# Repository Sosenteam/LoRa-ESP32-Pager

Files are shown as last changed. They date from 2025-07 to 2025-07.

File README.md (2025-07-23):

# LoRa-ESP32-Pager

This is a ESP-32 and SX1262 based pager, It contains full battery charging and management as well as an input keypad and encoder. It uses a 0.96" Oled (SSD1306).
There isn't any case because I wanted it to be a PCB only handheld (like the sprig), but I may laser cut a back when I get access to a laser cutter again (2 months).
The firmware is based on meshatastic, and hopefully will be able to use other meshtastic nodes to forward/mesh messages. 

I decided to build this because I felt like me and my friend group were too dependant on our phones, so I wanted to make a way to communicate that didn't involve phones. Also hopefully will be able to fully replace phones at school, which is aligned with my school possibly banning phones this upcoming year. The other main reason I wanted to start this project is because I wanted to learn more about radio and LoRa technology. This was also my first experience building my own PCBs, so I chose this over other projects because It would allow me to work with them.





|Name |Use |Qty|Total Price|Link |
|---|---|---|---|---|
|Oled Screen |Screen |5  |$9.80 |https://www.aliexpress.us/item/3256808552064563.html |
|Battery |Battery |5  |$23 |https://www.aliexpress.us/item/3256808031709894.html |
| | | | | |
|Ra-01SH |LoRa |5  |16.9 |https://www.aliexpress.us/item/3256802374880132.html |
|MCP73871-2CCI/ML |Battery Management |5  |8.7 |https://www.aliexpress.us/item/3256809154370435.html |
|ESP32-S3-WROOM-1 |ESP32 |5  |20.6 |https://www.aliexpress.us/item/3256808569536766.html |
|TPS63001DRCR |5v to 3v3 |5  |5.17 |https://www.aliexpress.us/item/3256806783602774.html (63001) |
|EC11E1834403 |Rotary Encoder |5  |4.14 |https://www.aliexpress.us/item/2251832760130101.html |
|TYPE-C 16PIN 2MD(073)  |Usb Plug |5  |2.69 |https://www.aliexpress.us/item/3256805314003507.html |
|All Resistors |R100Ω | |4.74 |https://www.aliexpress.us/item/3256806810055728.html (Buy 2-3) |
|Inductor 0805 2.2uH |Inductor for TPS63 |5  |1.45 |https://www.aliexpress.us/item/3256802926211468.html (2.2uH) |
|Leds |Battery Charge Leds  |10 |3.6 |https://www.aliexpress.us/item/2251832152971926.html |
|Diode 1N5819W |Diode for Usb Power  |5  |0.23 |https://www.digikey.com/en/products/detail/tdk-corporation/MLP2012H2R2MT0S1/4327857|
|Ph2.0 Battery Connector|Battery Charger |5  |1.45 |https://www.aliexpress.us/item/3256807255498839.html |
|PTS815SJM250SMTRLFS |Reset and Boot Button|10 |1.15 |https://www.digikey.com/en/products/detail/c-k/PTS815SJM250SMTRLFS/9947846 |
|6x6 Tact Switch |Keypad Buttons |3  |1.29 |https://www.aliexpress.us/item/3256802301084670.html |
|Capacitor Set |Decoupling |1  |8.2 |https://www.aliexpress.us/item/3256807290577536.html (Buy 2-3) |
|Diode LESD |ESD protection diodes|3  |3.34 |https://www.aliexpress.us/item/3256806903277344.html |
|Antenna |Ra-01SH antenna |5  |8.44 |https://www.aliexpress.us/item/3256805050972049.html |
|PCB |PCBs |5  |5 | |
|Ali Express Shipping | | |27 | |
|PCB Way Shipping | | |15 | |
|Digikey Shipping | | |7 | |
| | | |$178.89 | |

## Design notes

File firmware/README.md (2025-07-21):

# This is all TEST code, I can't write the meshtastic firmware untill I get the parts (I don't have this module or ESP32-s3).

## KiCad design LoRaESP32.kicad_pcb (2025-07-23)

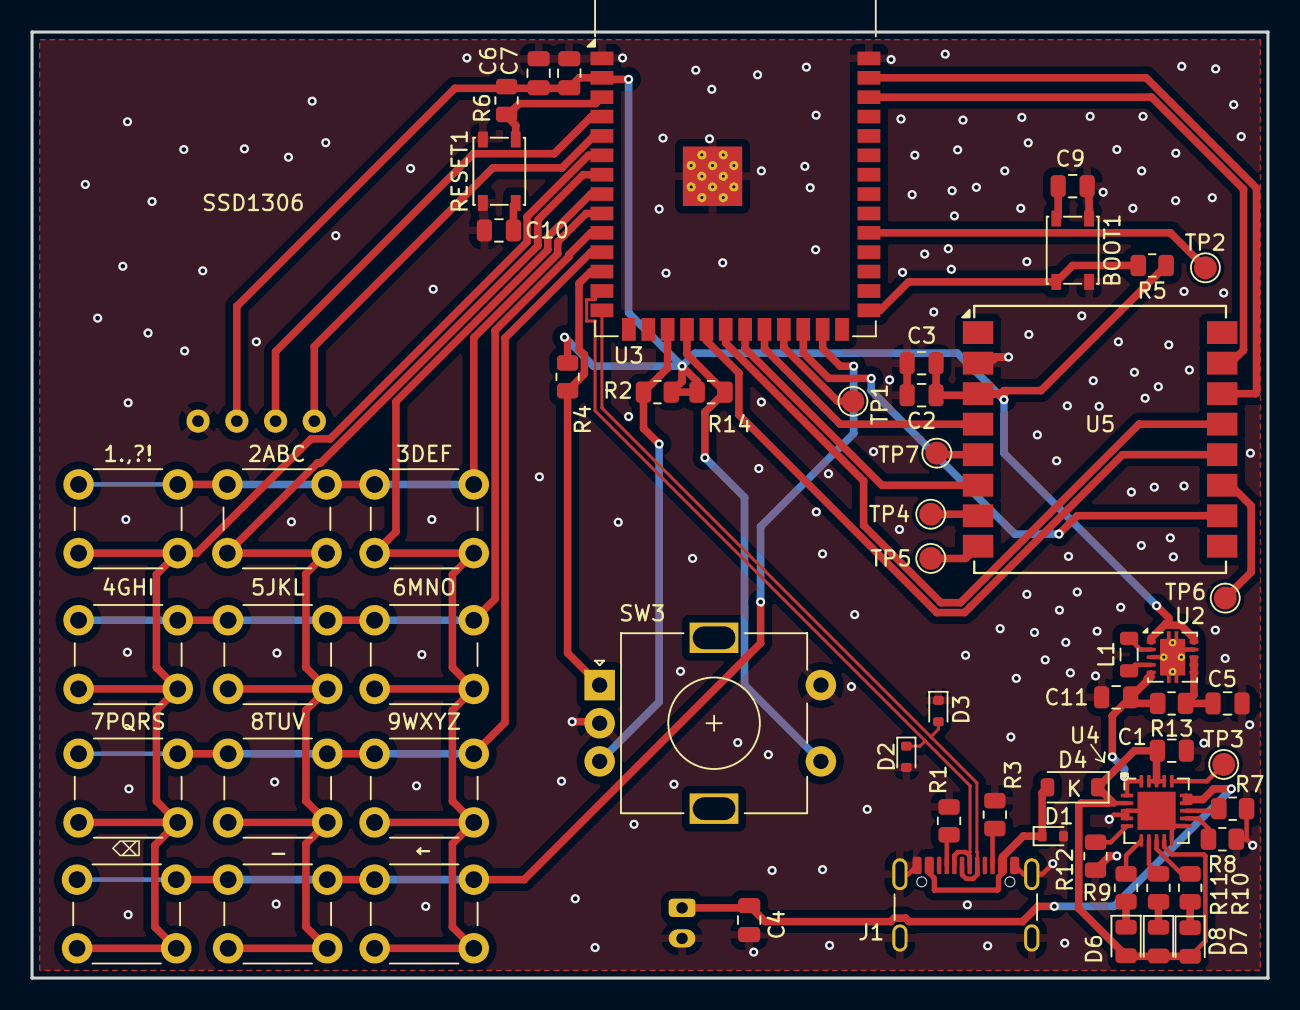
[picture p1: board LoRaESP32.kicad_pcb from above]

Board: 2 copper layers, 81.0 x 62.0 mm, 61 parts (1 on the bottom side), 50 nets.

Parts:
1.,?!, 2ABC, 3DEF, 4GHI, 5JKL, 6MNO, 7PQRS, 8TUV, 9WXYZ: B3SL-1002P; SW_PUSH_6mm
BOOT1: PTS815SJM250SMTRLFS; SW_SPST_PTS810
BT1: B2B-PH-K-S(LF)(SN); JST_PH_B2B-PH-K_1x02_P2.00mm_Vertical
C1, C2, C7, C11: 0805W106K250CC; C_0805_2012Metric
C3, C5, C6, C9, C10: 0805B104K500BD; C_0805_2012Metric
C4: 0805B475K250CC; C_0805_2012Metric
D1, D2, D3: LESD5D5.0CT1G; D_SOD-523
D4: 1N5819W; D_SOD-123
D6: LS R976-NR-1-0-20-R18; LED_0805_2012Metric
D7, D8: LY R97xLG R971-KN-1-0-20-R18; LED_0805_2012Metric
J1: TYPE-C 16PIN 2MD(073); USB_C_Receptacle_GCT_USB4105-xx-A_16P_TopMnt_Horizontal
L1: MLP2012 MLP2012H2R2MT0S1; L_0805_2012Metric
R1, R3: RC0805JR-075K1L; R_0805_2012Metric
R2, R4, R5, R6, R7, R8, R12, R14: RMCF0805FT10K0; R_0805_2012Metric
R9, R10, R11: CRGCQ0805J470R; R_0805_2012Metric
R13: RC0805FR-07100RL; R_0805_2012Metric
RESET1: PTS815SJM250SMTRLFS; SW_SPST_PTS810
SSD1306: SSD1306
SW3: EC11E1834403; RotaryEncoder_Alps_EC11E-Switch_Vertical_H20mm
TP1: TEST_GPIO_21; TestPoint_Pad_D1.5mm
TP2: TEST_GPIO_38; TestPoint_Pad_D1.5mm
TP3: BatTest; TestPoint_Pad_D1.5mm
TP4: DIO2; TestPoint_Pad_D1.5mm
TP5: DIO3; TestPoint_Pad_D1.5mm
TP6: RXEN; TestPoint_Pad_D1.5mm
TP7: TXEN; TestPoint_Pad_D1.5mm
U2: TPS63001; Texas_DRC0010J_ThermalVias
U3: ESP32-S3-WROOM-1
U4: MCP73871-2CC; QFN-20-1EP_4x4mm_P0.5mm_EP2.5x2.5mm
U5: Ra-01SH; Ai-Thinker-Ra-01-LoRa
_: B3SL-1002P; SW_PUSH_6mm
←: B3SL-1002P; SW_PUSH_6mm
⌫: B3SL-1002P; SW_PUSH_6mm

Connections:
+3V3: C2.1, C3.1, C6.1, C7.1, R2.2, R4.1, R5.1, R6.1, R14.1, SSD1306.2 (VCC), U2.1 (VOUT), U2.10 (FB), U3.2 (3V3), U5.3 (VDD)
+5V: C1.1, D4.1 (K), D6.2 (A), D7.2 (A), D8.2 (A), U4.2 (VPCC), U4.9 (~TE), U4.17 (CE), U4.18 (IN), U4.19 (IN)
CHIP_PU: C10.2, R6.2, RESET1.2, U3.3 (EN)
Col1: 1.,?!.2, 4GHI.2, 7PQRS.2, U3.6 (IO6), ⌫.2
Col2: 2ABC.2, 5JKL.2, 8TUV.2, U3.7 (IO7), _.2
Col3: 3DEF.2, 6MNO.2, 9WXYZ.2, U3.8 (IO15), ←.2
D+: D3.2 (A2), J1.A6 (D+), J1.B6 (D+), U3.14 (IO20)
D-: D2.1 (A1), J1.A7 (D-), J1.B7 (D-), U3.13 (IO19)
EncoderA: R4.2, SW3.A, U3.12 (IO8)
EncoderB: R2.1, SW3.B, U3.17 (IO9)
EncoderSW: R14.2, SW3.S1, U3.18 (IO10)
GND: BOOT1.1, BT1.2 (-), C1.2, C2.2, C3.2, C4.1, C5.2, C6.2, C7.2, C9.1, C10.1, C11.1, D1.2 (A2), D2.2 (A2), D3.1 (A1), J1.A1 (GND), J1.A12 (GND), J1.B1 (GND), J1.B12 (GND), J1.S1 (SHIELD), R1.2, R3.2, R7.1, R8.1, R12.1, RESET1.1, SSD1306.1 (GND), SW3.C, SW3.S2, U2.3 (PGND), U2.9 (GND), U2.11 (PGND), U3.1 (GND), U3.40 (GND), U3.41 (GND), U4.3 (SEL), U4.4 (PROG2), U4.10 (V_{SS}), U4.11 (V_{SS}), U4.21 (V_{SS}), U5.2 (GND)
GPIO_0: BOOT1.2, C9.2, R5.2, U3.27 (IO0)
LoraBUSY: U3.24 (IO47), U5.10 (BUSY)
LoraDIO1: U3.21 (IO13), U5.6 (DIO1)
LoraMISO: U3.20 (IO12), U5.13 (MISO)
LoraMOSI: U3.39 (IO1), U5.14 (MOSI)
LoraNSS: U3.38 (IO2), U5.15 (~NSS)
LoraRST: U3.22 (IO14), U5.4 (~RESET)
LoraSCK: U3.19 (IO11), U5.12 (SCK)
unnamed: BT1.1 (+), C4.2, U4.14 (V_{BAT}), U4.15 (V_{BAT})
unnamed: D1.1 (A1), D4.2 (A), J1.A4 (VBUS), J1.A9 (VBUS), J1.B4 (VBUS), J1.B9 (VBUS)
unnamed: D6.1 (K), R9.2
unnamed: D7.1 (K), R10.2
unnamed: D8.1 (K), R11.1
unnamed: J1.A5 (CC1), R1.1
unnamed: J1.B5 (CC2), R3.1
unnamed: C5.1, R13.1, U2.6 (EN), U2.7 (PS/SYNC), U2.8 (VINA)
unnamed: L1.2, U2.4 (L1)
unnamed: L1.1, U2.2 (L2)
unnamed: C11.2, R13.2, U2.5 (VIN), U4.1 (OUT), U4.20 (OUT)
unnamed: TP1.1, U3.23 (IO21)
unnamed: TP2.1, U3.31 (IO38)
unnamed: R7.2, U4.13 (PROG1)
unnamed: R8.2, U4.12 (PROG3)
unnamed: R10.1, U4.8 (STAT1/~LBO)
unnamed: R11.2, U4.7 (STAT2)
unnamed: R12.2, U4.5 (THERM)
unnamed: TP3.1, U4.16 (V_{BAT_SENSE})
unnamed: R9.1, U4.6 (~PG)
unnamed: TP4.1, U5.7 (DIO2)
unnamed: TP5.1, U5.8 (DIO3)
unnamed: TP6.1, U5.11 (RXEN)
unnamed: TP7.1, U5.5 (TXEN)
OledSCL: SSD1306.3 (SCL), U3.4 (IO4)
OledSDA: SSD1306.4 (SDA), U3.5 (IO5)
Row1: 1.,?!.1, 2ABC.1, 3DEF.1, U3.9 (IO16)
Row2: 4GHI.1, 5JKL.1, 6MNO.1, U3.10 (IO17)
Row3: 7PQRS.1, 8TUV.1, 9WXYZ.1, U3.11 (IO18)
Row4: U3.25 (IO48), _.1, ←.1, ⌫.1

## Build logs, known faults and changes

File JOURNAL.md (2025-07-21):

---
title: "LoRa ESP32 Pager"
author: "sosenteam"
description: "A P2P bidirectional pager using ESP32 and LoRa."
created_at: "2025-07-11"
---

# Total Time:  56.5 Hours

## 6/27/2025 (5 Hours)

First day working on this project!! I started by spending two-ish hours reading the specs on LoRa and learning the protocal.
[Amazing Tutorial for LoRa](https://www.circuitstate.com/tutorials/interfacing-ra-01-ra-02-sx1278-lora-modules-with-esp32-using-arduino/) -
[Module Spec Sheet](https://docs.ai-thinker.com/en/lora/man) -
[API Spec Sheet](https://github.com/sandeepmistry/arduino-LoRa/blob/master/API.md)

Afterwords I built the first prototype on a breadboard and got everything wired up.
Next, I messed around with the Arduino library for a while until I was able to send a message from one esp32 and receive it on my RTLSDR v4. Once I was able to send messages, I then built and wired an identical second prototype and got it to receive messages. After way too much tweaking, I was finally able to use a button to send a message from one to the other!

Picture of the protoypes (aren't they adorable):

LoRa Testing

## 6/28/2025 (2 Hours)

More research on how to display a UI! I picked out two SSD1306 modules (pictured above) I had on hand and decided to use them as my displays. I didn't want to manually code the entire UI so I started researching a less code-y solution. I discovered LVGL and Squareline Studio and starting setting them up, followed some Demo projects, read documentation etc.

## 6/29/2025 (2 Hours)

Started designing UI in Squareline Studio, got a first draft of the menu scren and started working on character selection with an encoder. I learned pretty quickly that Squareline studio is built for different projects, and it was also not very intuative to me.



## 7/01/2025 (1 Hour)

Continued work on the UI, focusiing on the read section (where incoming messages wil appear). Struggled a bit with getting the style how I wanted (not supposed to have blue), but overall happy with result.



## 7/04/2025 (2 Hours)

More UI Work! Got a finished version of the UI, with a send screen! Also has 'working' buttons, meaning the back buttons and main menu buttons now bring you to their respective pages. Exported to Arduino IDE!



## 7/05/2025 (1 Hour)

Disaster Struck! LVGL code is not built for the Arduino IDE (prefers the espressif IDE), and the libraries for Arduino are built for ESPI_TFT, which doesn't support my display.
Picture of what Squareline studio gave me:



#### 5 day skip from lack of motavation ):

## 7/10/2025 (3 Hours)

More reasearch done! I've decided to use the MUI library from the u8g2 library, because I've used u8g2 before for projects, and MUI has the encoder code setup!!!
I've also spent a while testing MUI and making and testing examples. Also added encoder to one prototype!

LoRa Update

## 7/11/2025 (2 Hours)

Lots more testing, Struggling with getting the screen to update quickly and also getting the encoder to have faster recognition/acceleration.

## 7/12/2025 (3 Hours)

Resolution!!! I figured out that in order to make the screen refresh faster, I needed to use hardware I2C instead of software I2C. I had to change a single character in my code from a S to a H. (So frustrating).
Also got a good demo for character selection, 12 characters, typing is 100x faster but still not quite perfect. I would like to get rid of Caps if I can. 

PXL_20250712_212104544 RAW-01 MP COVER

## 7/13/2025 (3 Hours)

Started work in KiCAD, lots of watching tutorials, and finding out how to use the editor. Started adding components to my schematic, such as ESP32, voltage regulator, etc.

## 7/14/2025 (3 Hours)

Lots more work in KiCAD, also lots of reading documentation/spec sheets. Started the power supply section, also picked out the ESP32-S3-WROOM-1 because it doesn't need a seperated UART>USB connector.



## 7/15/2025 (4.5 Hours)

So much more KiCAD, got USB and ESP32 and button sections of pcb done, started research into possible battery charging chips/boards (so scary).



 Also started figuring out placement for the board even though it's not great (not finished ofc).



## 7/16/2025 (4 Hours)

Redid entire power section, changed battery chip and voltage regulator chip. Added custom OLED, and also a button matrix. Also started hooking up everything to the ESP32 S3 Wroom.
 

## 7/17/2025 (3 Hours)

Pain. I realised that all my connections were net labels instead of global labels, so I had to redo them all. I added more decoupling caps, testing pads and battery connectors.



Also restarted the layout process and started grouping all my components (whitebox is hopeful final size)

## 7/18/2025 (5 Hours)

Lots of working on layouts. I did a first try of the layout, but I didn't know how to use ground planes so it wasn't very effective. Second draft went way better! I have a completed version, and have sent out pictures/information to Hackclub, KiCAD discord and r/PCB on reddit. Already have found a bunch of small things to fix!





## 7/19/2025 (5 Hours)

Spent the first half of today adressing most of the problems from my first draft. This included fixing symbols, rearranging pins on the ESP32 and adding pullups.
Afterwords I did a full do-over of my PCB layout, and made one more compact and simple. (also started looking into PCB pricing) 




## 7/20/2025 (4 Hours)

Discovered Meshtastic, and decided to attempt to make my board compatible w/ it. Ended up changing Ra-01 to Ra-01sh (diffrent LoRa Module). Redid some of layout (ADDED SO MANY VIAS), started looking into custom firmware.
Also uploaded to PCBway to see prices. (JLCPCB thinks its gonna be $300!!!).


## 7/21/2025 (4 Hours)

Looking at part sourcing, PCBway also wants $88 flat fee for assembly. Decided to assemble myself (scary). Some small pcb adjustments (for EMF), mostly spent today looking through AliExpress to find parts. Made a BOM and finished the rest of my Github repo so I can submit!!! 🎉

Final Pic:



### Thanks for reading all my random ramblings and progress updates!!

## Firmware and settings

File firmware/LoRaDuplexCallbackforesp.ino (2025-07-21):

/*
  LoRa Duplex communication wth callback

  Sends a message every half second, and uses callback
  for new incoming messages. Implements a one-byte addressing scheme,
  with 0xFF as the broadcast address.

  Note: while sending, LoRa radio is not listening for incoming messages.
  Note2: when using the callback method, you can't use any of the Stream
  functions that rely on the timeout, such as readString, parseInt(), etc.

  created 28 April 2017
  by Tom Igoe
*/
#include <SPI.h>              // include libraries
#include <LoRa.h>

#ifdef ARDUINO_SAMD_MKRWAN1300
#error "This example is not compatible with the Arduino MKR WAN 1300 board!"
#endif

const int csPin = 5;          // LoRa radio chip select
const int resetPin = 2;       // LoRa radio reset
const int irqPin = 4;         // change for your board; must be a hardware interrupt pin

String outgoing;              // outgoing message
byte msgCount = 0;            // count of outgoing messages
byte localAddress = 0xBB;     // address of this device
byte destination = 0xFF;      // destination to send to
long lastSendTime = 0;        // last send time
int interval = 2000;          // interval between sends

void setup() {
  Serial.begin(115200);                   // initialize serial
  while (!Serial);

  Serial.println("LoRa Duplex with callback");

  // override the default CS, reset, and IRQ pins (optional)
  LoRa.setPins(csPin, resetPin, irqPin);// set CS, reset, IRQ pin

  if (!LoRa.begin(433E6)) {             // initialize ratio at 915 MHz
    Serial.println("LoRa init failed. Check your connections.");
    while (true);                       // if failed, do nothing
  }

  LoRa.onReceive(onReceive);
  LoRa.receive();
  Serial.println("LoRa init succeeded.");
}

void loop() {
  if (millis() - lastSendTime > interval) {
    String message = "HeLoRa World!";   // send a message
    sendMessage(message);
    Serial.println("Sending " + message);
    lastSendTime = millis();            // timestamp the message
    interval = random(2000) + 1000;     // 2-3 seconds
    LoRa.receive();                     // go back into receive mode
  }
}

void sendMessage(String outgoing) {
  LoRa.beginPacket();                   // start packet
  LoRa.write(destination);              // add destination address
  LoRa.write(localAddress);             // add sender address
  LoRa.write(msgCount);                 // add message ID
  LoRa.write(outgoing.length());        // add payload length
  LoRa.print(outgoing);                 // add payload
  LoRa.endPacket();                     // finish packet and send it
  msgCount++;                           // increment message ID
}

void onReceive(int packetSize) {
  if (packetSize == 0) return;          // if there's no packet, return

  // read packet header bytes:
  int recipient = LoRa.read();          // recipient address
  byte sender = LoRa.read();            // sender address
  byte incomingMsgId = LoRa.read();     // incoming msg ID
  byte incomingLength = LoRa.read();    // incoming msg length

  String incoming = "";                 // payload of packet

  while (LoRa.available()) {            // can't use readString() in callback, so
    incoming += (char)LoRa.read();      // add bytes one by one
  }

  if (incomingLength != incoming.length()) {   // check length for error
    Serial.println("error: message length does not match length");
    return;                             // skip rest of function
  }

  // if the recipient isn't this device or broadcast,
  if (recipient != localAddress && recipient != 0xFF) {
    Serial.println("This message is not for me.");
    return;                             // skip rest of function
  }

  // if message is for this device, or broadcast, print details:
  Serial.println("Received from: 0x" + String(sender, HEX));
  Serial.println("Sent to: 0x" + String(recipient, HEX));
  Serial.println("Message ID: " + String(incomingMsgId));
  Serial.println("Message length: " + String(incomingLength));
  Serial.println("Message: " + incoming);
  Serial.println("RSSI: " + String(LoRa.packetRssi()));
  Serial.println("Snr: " + String(LoRa.packetSnr()));
  Serial.println();
}

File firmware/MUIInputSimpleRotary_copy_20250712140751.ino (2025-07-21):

/*

  MUIInputSimpleRotary.ino

  MUI: https://github.com/olikraus/u8g2/wiki/muimanual
  U8g2 Menu with Rotary Encoder (SimpleRotary library).
  
  Universal 8bit Graphics Library (https://github.com/olikraus/u8g2/)

  Copyright (c) 2022, olikraus@gmail.com
  All rights reserved.

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
  THIS SOFTWARE IS PROVIDED BY THE COPYRIGHT HOLDERS AND 
  CONTRIBUTORS "AS IS" AND ANY EXPRESS OR IMPLIED WARRANTIES, 
  INCLUDING, BUT NOT LIMITED TO, THE IMPLIED WARRANTIES OF 
  MERCHANTABILITY AND FITNESS FOR A PARTICULAR PURPOSE ARE 
  DISCLAIMED. IN NO EVENT SHALL THE COPYRIGHT HOLDER OR 
  CONTRIBUTORS BE LIABLE FOR ANY DIRECT, INDIRECT, INCIDENTAL, 
  SPECIAL, EXEMPLARY, OR CONSEQUENTIAL DAMAGES (INCLUDING, BUT 
  NOT LIMITED TO, PROCUREMENT OF SUBSTITUTE GOODS OR SERVICES; 
  LOSS OF USE, DATA, OR PROFITS; OR BUSINESS INTERRUPTION) HOWEVER 
  CAUSED AND ON ANY THEORY OF LIABILITY, WHETHER IN CONTRACT, 
  STRICT LIABILITY, OR TORT (INCLUDING NEGLIGENCE OR OTHERWISE) 
  ARISING IN ANY WAY OUT OF THE USE OF THIS SOFTWARE, EVEN IF 
  ADVISED OF THE POSSIBILITY OF SUCH DAMAGE.  

*/

#include <Arduino.h>
#include <U8g2lib.h>
#include <MUIU8g2.h>
#include <SimpleRotary.h>

// SimpleRotary Library
// https://github.com/mprograms/SimpleRotary
// Pin A, Pin B, Button Pin
SimpleRotary rotary(25,26,27);

U8G2_SSD1306_128X64_NONAME_F_HW_I2C u8g2(U8G2_R0, /* clock=*/ 22, /* data=*/ 21, /* reset=*/ U8X8_PIN_NONE);   // All Boards without Reset of the Display


MUIU8G2 mui;

/*
  global variables which form the communication gateway between the user interface and the rest of the code
*/
char s[13] = "            ";



uint8_t mui_hrule(mui_t *ui, uint8_t msg) {
  if ( msg == MUIF_MSG_DRAW ) {
      u8g2.drawHLine(0, mui_get_y(ui), u8g2.getDisplayWidth());
  }
  return 0;
}

uint8_t show_my_data(mui_t *ui, uint8_t msg) {
  if ( msg == MUIF_MSG_DRAW ) {
    u8g2_uint_t x = mui_get_x(ui);
    u8g2_uint_t y = mui_get_y(ui);
    u8g2.setCursor(x+5, y);
    u8g2.print("Word:");
    // u8g2.setCursor(x+50, y);
    // u8g2.print(num_value);

    // u8g2.setCursor(x+5, y+12);
    // u8g2.print("Bar:");
    // u8g2.setCursor(x+50, y+12);
    // u8g2.print(bar_value);

    // u8g2.setCursor(x+5, y+24);
    // u8g2.print("Animal:");
    // u8g2.setCursor(x+50, y+24);
    // u8g2.print(animal_idx);  
    // u8g2.print("=");  
    // u8g2.print(animals[animal_idx]);  
  }
  return 0;
}

muif_t muif_list[] = {
  MUIF_U8G2_FONT_STYLE(0, u8g2_font_helvR08_tr),        /* regular font */
  MUIF_U8G2_FONT_STYLE(1, u8g2_font_helvB08_tr),        /* bold font */
  MUIF_U8G2_FONT_STYLE(5, u8g2_font_profont12_mf),        //monospaced also try 'u8g2_font_spleen6x12_mf' or 'u8g2_font_t0_12_mf'

  MUIF_RO("HR", mui_hrule),
  MUIF_U8G2_LABEL(),
  MUIF_RO("GP",mui_u8g2_goto_data),  
  MUIF_BUTTON("GC", mui_u8g2_goto_form_w1_pi),
  
  MUIF_VARIABLE("T0",s+0,mui_u8g2_u8_char_wm_mud_pi),
  MUIF_VARIABLE("T1",s+1,mui_u8g2_u8_char_wm_mud_pi),
  MUIF_VARIABLE("T2",s+2,mui_u8g2_u8_char_wm_mud_pi), 
  MUIF_VARIABLE("T3",s+3,mui_u8g2_u8_char_wm_mud_pi),
  MUIF_VARIABLE("T4",s+4,mui_u8g2_u8_char_wm_mud_pi),
  MUIF_VARIABLE("T5",s+5,mui_u8g2_u8_char_wm_mud_pi),
  MUIF_VARIABLE("T6",s+6,mui_u8g2_u8_char_wm_mud_pi), 
  MUIF_VARIABLE("T7",s+7,mui_u8g2_u8_char_wm_mud_pi),
  MUIF_VARIABLE("T8",s+8,mui_u8g2_u8_char_wm_mud_pi),
  MUIF_VARIABLE("T9",s+9,mui_u8g2_u8_char_wm_mud_pi),
  MUIF_VARIABLE("TA",s+10,mui_u8g2_u8_char_wm_mud_pi), 
  MUIF_VARIABLE("TB",s+11,mui_u8g2_u8_char_wm_mud_pi),

  // MUIF_U8G2_U8_MIN_MAX("NV", &num_value, 0, 99, mui_u8g2_u8_min_max_wm_mud_pi),
  // MUIF_U8G2_U8_MIN_MAX_STEP("NB", &bar_value, 0, 16, 1, MUI_MMS_2X_BAR, mui_u8g2_u8_bar_wm_mud_pf),
  // MUIF_U8G2_U16_LIST("NA", &animal_idx, NULL, animal_name_list_get_str, animal_name_list_get_cnt, mui_u8g2_u16_list_line_wa_mud_pi),

  /* register custom function to show the data */
  MUIF_RO("SH", show_my_data), 

  /* a button for the menu... */
  MUIF_BUTTON("GO", mui_u8g2_btn_goto_wm_fi)  
};


fds_t fds_data[] = 

MUI_FORM(1)
MUI_STYLE(1)
MUI_LABEL(5, 8, "SimpleRotary Lib")
MUI_STYLE(0)
MUI_XY("HR", 0,11)
MUI_DATA("GP", 
    MUI_10 "Enter Data|"
    MUI_12 "Show Data")
MUI_XYA("GC", 5, 24, 0) 
MUI_XYA("GC", 5, 36, 1) 

MUI_FORM(10)
// MUI_STYLE(1)
// MUI_LABEL(5, 8, "Enter Data")
// MUI_XY("HR", 0,11)
// MUI_STYLE(0)
// MUI_LABEL(5,23, "Word:")
// MUI_XYAT("GO", 114, 60, 1, " Ok ") 

// MUI_FORM(61)
MUI_STYLE(0)
MUI_LABEL(5,20, "Text:")
MUI_STYLE(5)                        /* use a monospaced font */
MUI_XY("T0",20, 40)
MUI_XY("T1",28, 40)
MUI_XY("T2",36, 40)
MUI_XY("T3",44, 40)
MUI_XY("T4",52, 40)
MUI_XY("T5",60, 40)
MUI_XY("T6",68, 40)
MUI_XY("T7",76, 40)
MUI_XY("T8",84, 40)
MUI_XY("T9",92, 40)
MUI_XY("TA",100, 40)
MUI_XY("TB",108, 40)
MUI_STYLE(0)
MUI_XYAT("GO", 114, 60, 1, " Ok ") 

MUI_FORM(12)
MUI_STYLE(1)
MUI_LABEL(5, 8, "Show Data")
MUI_XY("HR", 0,11)
MUI_STYLE(0)
MUI_XY("SH", 0, 23)
MUI_XYAT("GO", 114, 60, 1, " Ok ") 

;


void setup(void) {
  u8g2.begin();
  mui.begin(u8g2, fds_data, muif_list, sizeof(muif_list)/sizeof(muif_t));
  mui.gotoForm(/* form_id= */ 1, /* initial_cursor_position= */ 0);
}

uint8_t is_redraw = 1;
uint8_t rotary_event = 0; // 0 = not turning, 1 = CW, 2 = CCW
uint8_t push_event = 0; // 0 = not pushed, 1 = pushed

void detect_events(void) {
  uint8_t tmp;
  
  // 0 = not pushed, 1 = pushed  
  tmp = rotary.push();
  if ( tmp != 0 )         // only assign the push event, never clear the event here
    push_event = tmp;
    
  // 0 = not turning, 1 = CW, 2 = CCW
  tmp = rotary.rotate();
  if ( tmp != 0 )       // only assign the rotation event, never clear the event here
    rotary_event = tmp;    
}

void handle_events(void) {
  // 0 = not pushed, 1 = pushed  
  if ( push_event == 1 ) {
      mui.sendSelect();
      is_redraw = 1;
      push_event = 0;
  }
  
  // 0 = not turning, 1 = CW, 2 = CCW
  if ( rotary_event == 1 ) {
    mui.nextField();
    is_redraw = 1;
    rotary_event = 0;
  }
  
  if ( rotary_event == 2 ) {
    mui.prevField();
    is_redraw = 1;
    rotary_event = 0;
  }    
}


void loop(void) {

  /* check whether the menu is active */
  if ( mui.isFormActive() ) {

    /* update the display content, if the redraw flag is set */
    if ( is_redraw ) {
      u8g2.firstPage();
      do {
          detect_events();
          mui.draw();
          detect_events();
      } while( u8g2.nextPage() );
      is_redraw = 0;                    /* clear the redraw flag */
    }

    detect_events();
    handle_events();
      
  } else {
      /* the menu should never become inactive, but if so, then restart the menu system */
      mui.gotoForm(/* form_id= */ 1, /* initial_cursor_position= */ 0);
  }
}

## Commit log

2025-07-21 Update and rename Lora BOM - Req for 5 Boards.csv to BOM.csv
    [BOM.csv]
2025-07-23 Fix PCB Layout Picture
